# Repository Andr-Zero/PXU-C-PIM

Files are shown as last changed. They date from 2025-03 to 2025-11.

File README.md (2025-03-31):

# PXU USB-C Power Input Module (PIM)
## _Power your OG Xbox via a USB Charger!_

This is based off the [SparkFun USB-C Power Delivery Board](https://github.com/sparkfun/Power_Delivery_Board-USB-C)

##### Disclaimer!
- I'm not an Electrical Engineer. Just wanted to make something cool and challenge myself.
- The OEM power supply can hold a potentially dangerous charge even after being unplugged for a large period of time!
- Your USB-C Cable MUST be capable of handling 100w! Lot out here that’s only 65w and most don’t have markings saying what their limits are. 
- You're on your own, I'm not responsible for injury or damages. 

##### TODO
- Photos
- Install instruction
- Upload Arduino code for programming
- Upload board and design files
- Explain header, programming, and LEDs

##### FAQ
- What chargers work?  
  I dont have a definitive list. Any 100w charger *should* work. I tested with an Anker 100w I got off Amazon and have had no issues.
- Does it have to be a 100w charger?  
   At a minimum, YES! There's a lot of 65w chargers out there and they simply not enough to power a *stock* console.
- I'm plugging in my charger but nothing is working.  
   The charger has to be able to negotiate with the PIM saying it can do ~100w at 20v, otherwise the PIM refuses to pass power.
- My USB charger is warm when running the console, is that normal?  
   Depends on the charger, mine does and with anything I use it with. Apperently the GaN chargers run cooler? I've yet to verify myself.
- My USB-C Cable is hot or has melted down!  
   It wasn’t rated for 100w. MUST use a cable that’s rated for 100w.

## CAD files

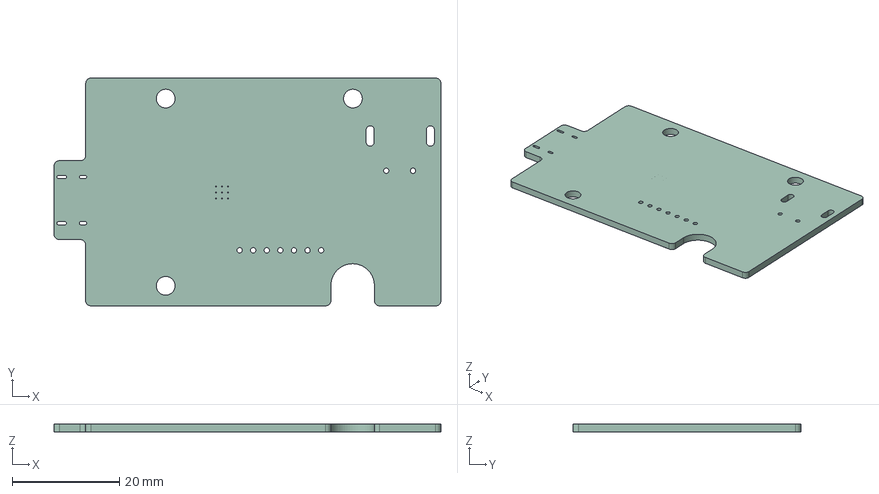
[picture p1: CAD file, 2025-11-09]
KiCad/C-PIM.step
72.3 x 42.6 x 1.51 mm

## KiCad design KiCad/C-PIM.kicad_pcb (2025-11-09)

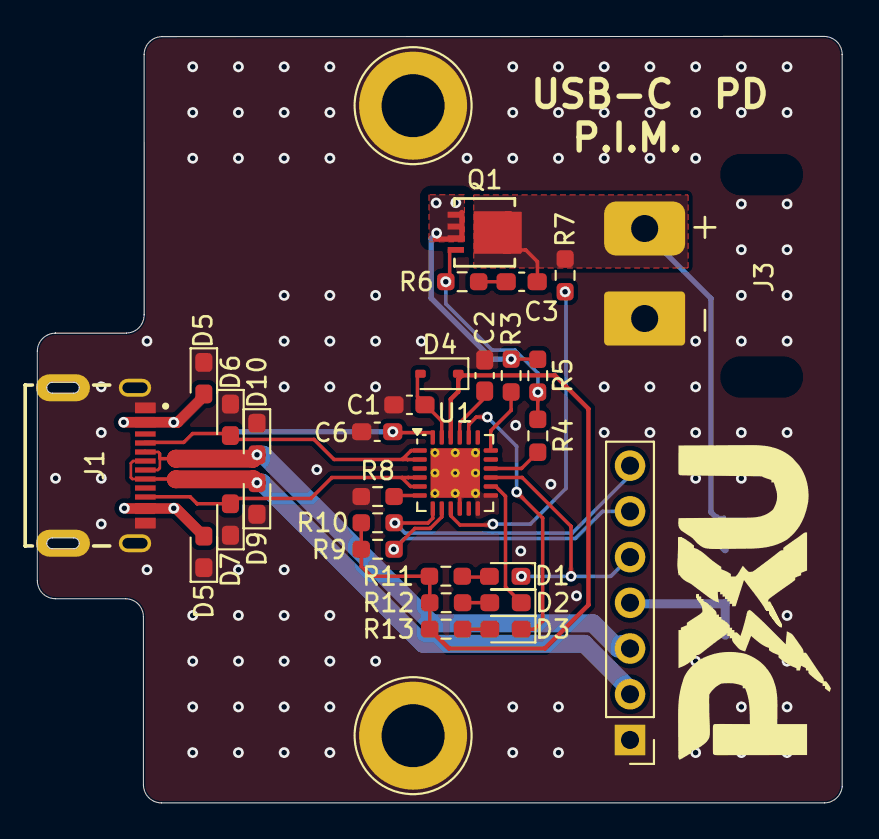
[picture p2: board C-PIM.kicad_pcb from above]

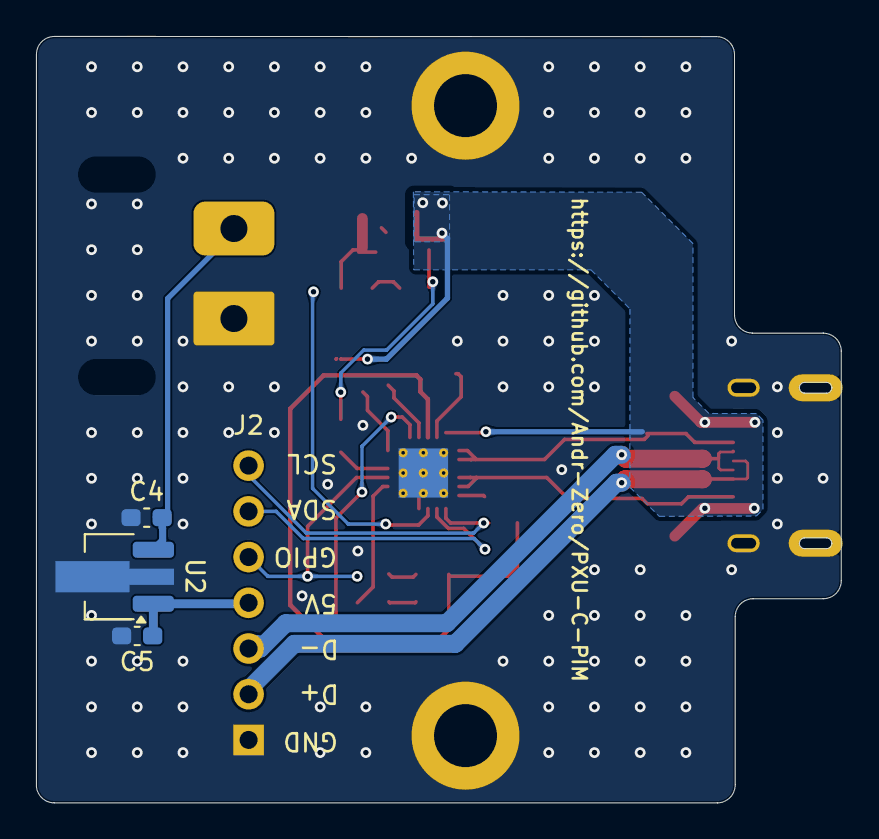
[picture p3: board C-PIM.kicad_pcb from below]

Board: 2 copper layers, 44.7 x 42.6 mm, 33 parts (4 on the bottom side), 25 nets.

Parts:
C1, C2, C3, C4, C5, C6: 1uF 25v; C_0603_1608Metric_Pad1.08x0.95mm_HandSolder
D1: RED; LED_0603_1608Metric_Pad1.05x0.95mm_HandSolder
D2: Green; LED_0603_1608Metric_Pad1.05x0.95mm_HandSolder
D3: Yellow; LED_0603_1608Metric_Pad1.05x0.95mm_HandSolder
D4: BAT60A; D_SOD-323
D5, D5#2, D6, D7, D9, D10: 24V; D_0603_1608Metric_Pad1.05x0.95mm_HandSolder
J1: USB4215-03-A_REVA; GCT_USB4215-03-A_REVA
J2: CONN_07NO_SILK; PinHeader_1x07_P2.54mm_Vertical
J3: Conn_01x02_Pin; AMASS_XT30PW-M_1x02_P2.50mm_Horizontal
Q1: 9A/30V/15mΩ; POWERFLAT_3P3X3P3_STM
R3, R7, R11, R12, R13: 1k; R_0603_1608Metric_Pad0.98x0.95mm_HandSolder
R4: 22k; R_0603_1608Metric_Pad0.98x0.95mm_HandSolder
R5, R8: 100k; R_0603_1608Metric_Pad0.98x0.95mm_HandSolder
R6: 100r; R_0603_1608Metric_Pad0.98x0.95mm_HandSolder
R9, R10: 4.7k; R_0603_1608Metric_Pad0.98x0.95mm_HandSolder
U1: STUSB4500; QFN-24-1EP_4x4mm_P0.5mm_EP2.75x2.75mm_ThermalVias
U2: AP7375Q-50Y-13; SOT-89-3_Handsoldering

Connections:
5vReg: C5.1, J2.4, U2.3 (VI)
/CC1: D6.2 (C), J1.A5 (CC1), U1.1 (CC1DB), U1.2 (CC1)
/CC2: D7.2 (C), J1.B5 (CC2), U1.4 (CC2), U1.5 (CC2DB)
/D+: D9.2 (C), J1.A6 (DP1), J1.B6 (DP2), J2.2
/D-: D10.2 (C), J1.A7 (DN1), J1.B7 (DN2), J2.3
/GPIO: D1.1 (K), J2.5, U1.15 (GPIO)
/POWER_PDO2: D3.1 (K), U1.20 (POWER_OK2)
/POWER_PDO3: D2.1 (K), U1.14 (POWER_OK3)
GND: C1.2, C2.2, C4.2, C5.2, C6.2, D5.1 (A), D5#2.1 (A), D6.1 (A), D7.1 (A), D9.1 (A), D10.1 (A), J1.A1_B12 (GND_A), J1.B1_A12 (GND_B), J1.SH1 (SHIELD), J1.SH2 (SHIELD), J2.1, J3.2, R8.1, U1.10 (GND), U1.12 (ADDR0), U1.13 (ADDR1), U1.25 (GND), U2.2 (GND)
unnamed: C3.2, R6.2
unnamed: D1.2 (A), R11.1
unnamed: D2.2 (A), R12.1
unnamed: D3.2 (A), R13.1
unnamed: C1.1, D4.2 (A), U1.23 (VREG_2V7)
unnamed: Q1.4 (G), R4.2, R5.1, R6.1
unnamed: R7.2, U1.9 (DISCH)
unnamed: R8.2, U1.6 (RESET)
unnamed: J2.7, R10.1, U1.7 (SCL)
unnamed: J2.6, R9.1, U1.8 (SDA)
unnamed: R4.1, U1.16 (VBUS_EN_SNK)
unnamed: R3.1, U1.18 (VBUS_VS_DISCH)
unnamed: C2.1, U1.21 (VREG_1V2)
VDD: D4.1 (K), R9.2, R10.2, R11.2, R12.2, R13.2, U1.22 (VSYS)
VIN: C6.1, D5.2 (C), D5#2.2 (C), J1.A4_B9 (VBUS_A), J1.B4_A9 (VBUS_B), Q1.1 (S), Q1.2 (S), Q1.3 (S), R3.2, R5.2, U1.24 (VDD)
VSNK: C3.1, C4.1, J3.1, Q1.5 (D), Q1.6 (D), Q1.7 (D), Q1.8 (D), R7.1, U2.1 (VO)

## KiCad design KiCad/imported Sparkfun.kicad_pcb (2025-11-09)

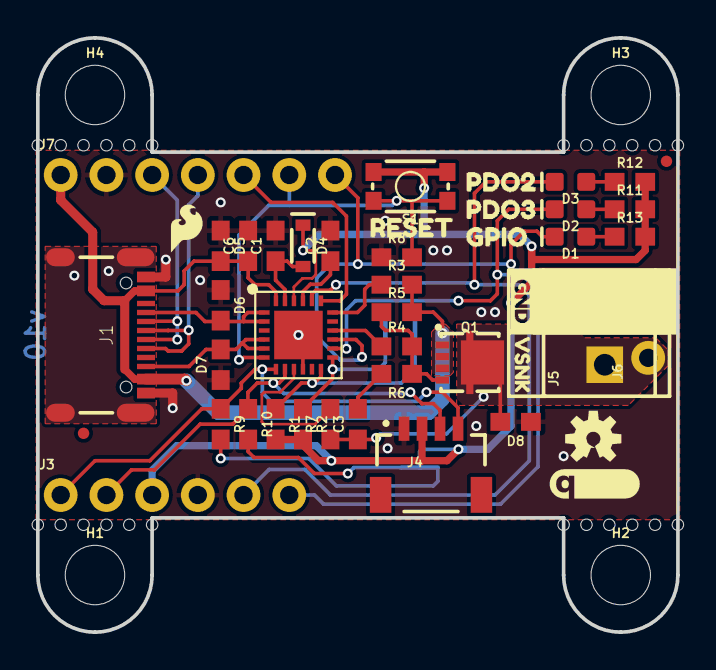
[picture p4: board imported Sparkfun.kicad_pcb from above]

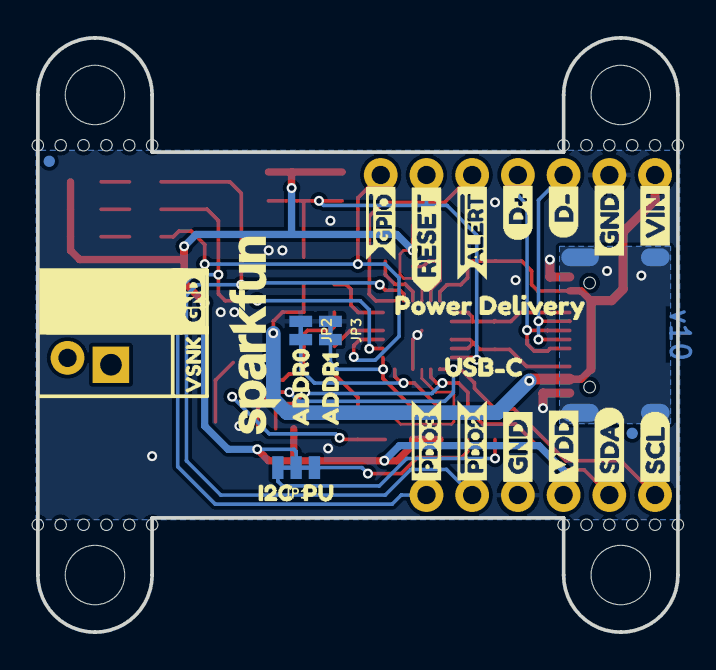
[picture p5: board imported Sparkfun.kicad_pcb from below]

Board: 2 copper layers, 35.6 x 33.0 mm, 101 parts (27 on the bottom side), 30 nets.

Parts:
@HOLE0, @HOLE1, @HOLE2, @HOLE3, @HOLE4, @HOLE5, @HOLE6, @HOLE7, @HOLE8, @HOLE9, @HOLE10, @HOLE11, @HOLE12, @HOLE13, @HOLE14, @HOLE15, @HOLE16, @HOLE17, @HOLE18, @HOLE19, @HOLE20, @HOLE21, @HOLE22, @HOLE23: (no value)
C1, C2, C6: 1.0uF; 0603
C3: 0.1uF; 0603
D1: BLUE; LED-0603
D2: Yellow; LED-0603
D3: GREEN; LED-0603
D4: BAT60A; SOD-323
D5, D6, D7, D8: 24V; 0603
FD1, FD2, FD3, FD4: FIDUCIALUFIDUCIAL; FIDUCIAL-MICRO
FRAME1: FRAME-LETTER; CREATIVE_COMMONS
H1, H2, H3, H4: STAND-OFF
J1: USB-C-16P
J3: 1X06_NO_SILK
J4: QWIIC; JST04_1MM_RA
J5: SCREWTERMINAL-3.5MM-2
J6: 1X02_NO_SILK
J7: 1X07_NO_SILK
JP1: SMT-JUMPER_3_2-NC_TRACE_NO-SILK
JP2, JP3: SMT-JUMPER_2_NC_TRACE_NO-SILK
LOGO1: OSHW-LOGOS; OSHW-LOGO-S
LOGO2: SFE_LOGO_NAME.1_INCH; SFE_LOGO_NAME_.1
LOGO3: QWIIC_LOGO_5MM; QWIIC_5MM
Q1: 9A/30V/15mΩ; 8-POWERVDFN-3X3
R1, R2, R5, R8: 100k; 0603
R3, R7, R11, R12, R13: 1k; 0603
R4: 22k; 0603
R6: 100; 0603
R9, R10: 2.2k; 0603
S1: TACTILE_SWITCH_SMD_4.6X2.8MM
U1: STUSB4500; QFN-24
U$1: VDD2
U$2, U$11: GND6
U$3: SDA11
U$4: SCL12
U$5: #GPIO0
U$7: D#8
U$8: D#7
U$9: USB#C1
U$10: RESET10
U$12: VIN6
U$13: I2C2
U$14: PU3
U$15: ADDR00
U$16: ADDR11
U$17: RESET7
U$18: GPIO1
U$19: PDO24
U$20: PDO35
U$21, U$24: VSNK1
U$22, U$23: GND0
U$25: SFE_LOGO_FLAME_.1
U$26: #ALERT0
U$27: _POWER_DELIVERY2
U$29: #PDO20
U$30: #PDO31

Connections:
1.2V: C2.1, U1.P$21
2.7V: C1.1, D4.A, U1.P$23
ADDR0: JP2.2, R1.1, U1.P$12
ADDR1: JP3.2, R2.1, U1.P$13
CC1: D6.2, J1.A5, U1.P$1, U1.P$2
CC2: D7.2, J1.B5, U1.P$4, U1.P$5
D+: J1.A6, J1.B6, J7.4
D-: J1.A7, J1.B7, J7.3
DISCH: R7.2, U1.P$9
EN_SNK: R4.1, U1.P$16
GND: C1.2, C2.2, C6.2, D5.1, D6.1, D7.1, D8.1, J1.GND, J1.GND2, J3.4, J4.1, J5.2, J6.2, J7.2, JP2.1, JP3.1, R8.1, U1.P$10, U1.P$25
GPIO: D1.C, J7.7, U1.P$15
unnamed: D2.A, R11.1
unnamed: D3.A, R12.1
unnamed: JP1.3, R9.2
unnamed: JP1.1, R10.2
unnamed: Q1.4, R4.2, R5.1, R6.1
unnamed: C3.2, R6.2
unnamed: D1.A, R13.1
POWER_PDO2: D3.C, J3.5, U1.P$20
POWER_PDO3: D2.C, J3.6, U1.P$14
RESET: J7.6, R8.2, S1.3, S1.4, U1.P$6
SCL: J3.1, J4.4, R9.1, U1.P$7
SDA: J3.2, J4.3, R10.1, U1.P$8
SHIELD: J1.SHLD1, J1.SHLD2, J1.SHLD3, J1.SHLD4, J1.SHLD5, J1.SHLD6, J1.SHLD7, J1.SHLD8
VBUS_VS_DISCH: R3.1, U1.P$18
VDD: D4.C, J3.3, J4.2, JP1.2, R1.2, R2.2, R11.2, R12.2, R13.2, S1.1, S1.2, U1.P$22
VIN: C6.1, D5.2, J1.VBUS1, J1.VBUS2, J7.1, Q1.1, Q1.2, Q1.3, R3.2, R5.2, U1.P$24
VSNK: C3.1, D8.2, J5.1, J6.1, Q1.5@1, Q1.5@2, Q1.5@3, R7.1
~ALERT: J7.5, U1.P$19

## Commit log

2025-11-09 Rev2 of the USB Module
    [C-PIM.kicad_pcb, C-PIM.kicad_sch, C-PIM.step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]
2025-11-09 Clean Upload
    [C-PIM.kicad_pcb, C-PIM.kicad_sch, C-PIM.step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]
2025-11-21 RE-Attach Readme
    Failed to pay attention on how I was pushing.

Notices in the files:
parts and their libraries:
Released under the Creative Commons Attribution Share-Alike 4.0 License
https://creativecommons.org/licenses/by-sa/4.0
